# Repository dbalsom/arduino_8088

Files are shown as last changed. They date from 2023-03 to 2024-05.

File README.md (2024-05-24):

# Arduino8088
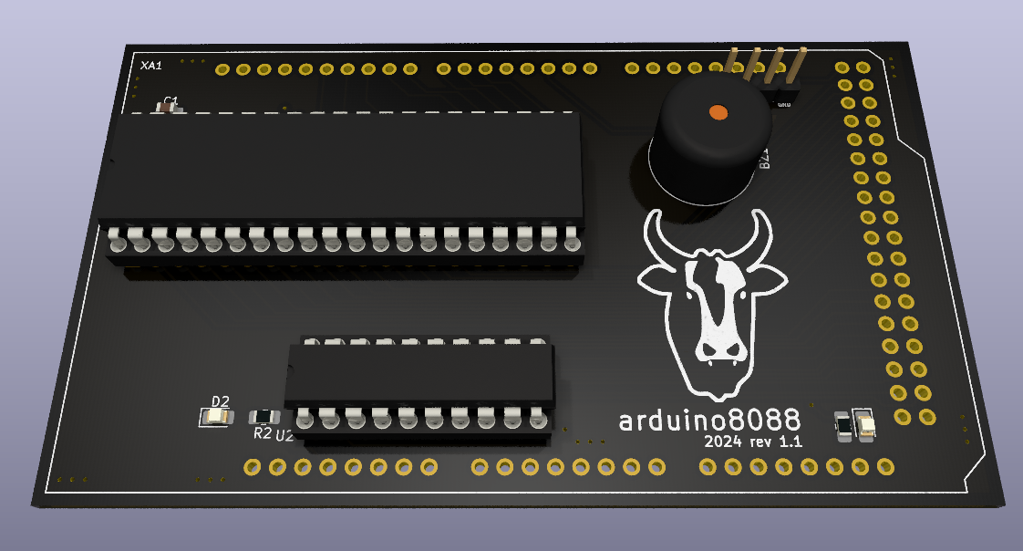
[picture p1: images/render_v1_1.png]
arduino8088_pcb


### About Arduino8088
I've writtten a blog article that gives an overview of this project and how it is used.

https://martypc.blogspot.com/2023/06/hardware-validating-emulator.html

### Description

This project expands on the basic idea of controlling an Intel 8088 or NEC V20 CPU via GPIO pins to clock the CPU and read and write control and data signals.
This can be used to validate an emulator's accuracy, but also as a general method of exploring the operation of 8088 and V20 instructions and timings.

Where it differs from Raspberry Pi based projects is that it uses an Arduino DUE to supply enough GPIO pins to operate the 8088 in Maximum mode without requiring any shifters. This enables several useful signals to be read such as the QS0 & QS1 processor instruction queue status lines, which give us more insight into the internal state of the CPU. We can also enable inputs such as READY, NMI, INTR, and TEST, so we can in theory execute interrupts, emulate wait states, and perhaps simulate FPU and DMA operations.

The board supports an Intel 8288 bus controller which can produce bus signals, but this chip is optional as the sketch can perform i8288 emulation.

The original Arduino8088 board utilized an Arduino MEGA, but this board is now considered deprecated for this project. As of the current release, an [Arduino DUE](https://store.arduino.cc/products/arduino-due) should be used instead. Although the DUE has 3v GPIO, the current board design is modified for 3V operation.  The 80C88 itself tolerates 3V well, and i8288 emulation can be used if you lack a CMOS 8288.

I have been using this project to validate the cycle-accuracy of my PC emulator, MartyPC: https://github.com/dbalsom/martypc 

## Can the CPU be clocked fast enough?

In short, no. We are well past the published minimum cycle times when executing programs via a serial protocol, cycle by cycle. Some chips tolerate this better than others. When working with an Intel branded 8088, I noticed that effective address calculations were failing to add the displacement or index register, but otherwise functioned. I have had more luck with the AMD second-source 8088 CPUs, which seem to function perfectly under slow clocks although they will hang and need to be reset if not cycled for a several milliseconds. The issue is "dynamic logic" - logic gates that lose their state if not refrehsed electrically within a frequent enough interval. To be absolutely safe, it is best to use a fully CMOS process CPU such as the 80C88. 

## Credits

Inspired by and borrows from the Pi8088 validator created by Andreas Jonsson as part of the VirtualXT project:

https://github.com/andreas-jonsson/virtualxt/tree/develop/tools/validator/pi8088

A very similar project is homebrew8088's Raspberry Pi Hat:

https://github.com/homebrew8088/pi86

## To use

If you don't want to order and build the PCB, connect the GPIO pins to the CPU on a breadboard as specified in the KiCad project schematic.

The main Arduino8088 sketch, cpu_server, operates a simple binary serial protocol to execute operations on the CPU and read and write data, status and control signals. This is designed for integration with an emulator or instruction test generator.

Additionally there is a sketch, 'run_program', that will take any user-supplied register state and array of instruction bytes defined in the source code, execute it, and print cycle traces and final register state. This is useful for investigating the timing and operation of certain instructions without needing any external software integrations, however it is restricted in the number of memory reads or writes it can support, due to the limited RAM on the Arduino MEGA (8k!) 'run_program' does not currently support the DUE.

An example client for cpu_server is provded, written in Rust, in the client directory. It demonstrates how to upload arbitrary code to the Arduino8088 and display cycle traces. The client will emulate the entire address space and set up a basic IVT.

## PCB
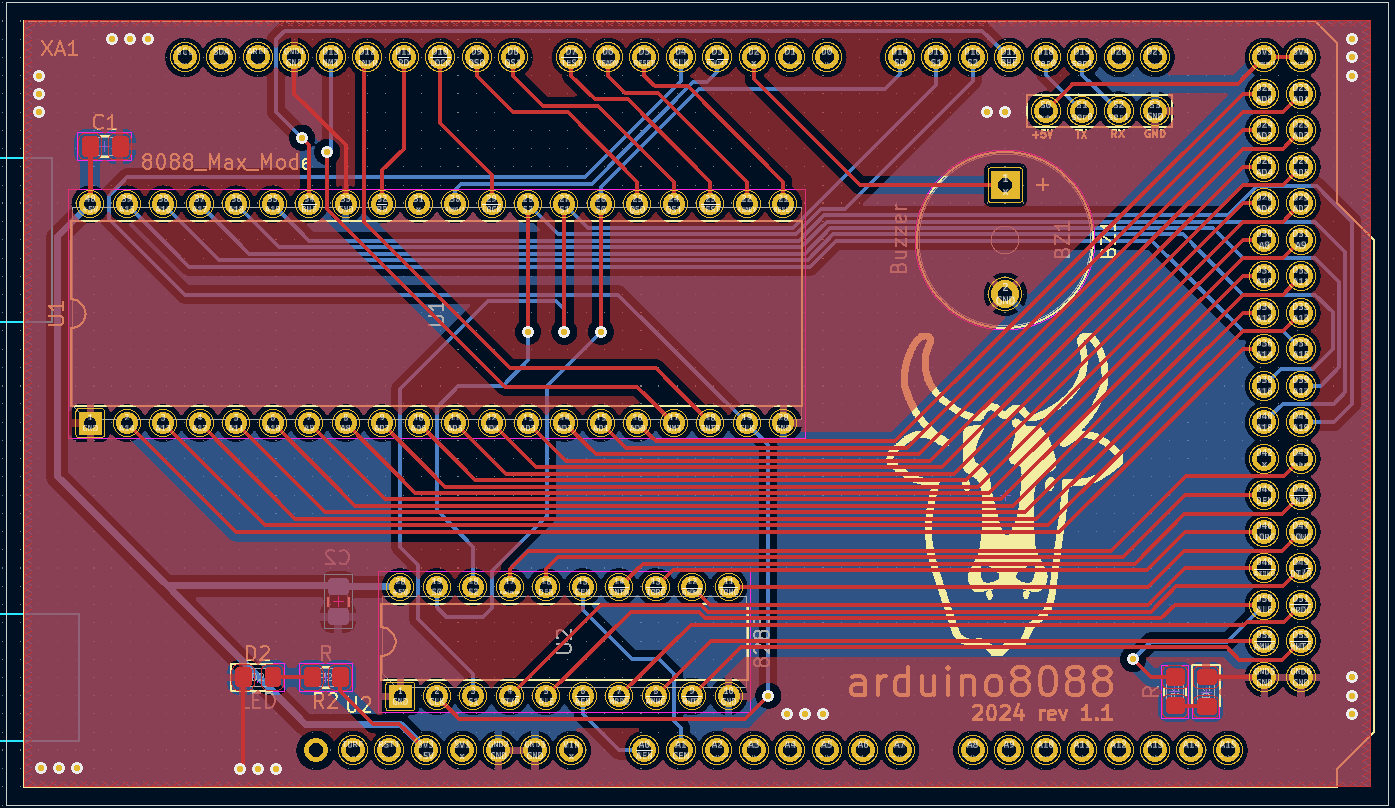
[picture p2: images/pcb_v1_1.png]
pcb_shield50


KiCad project files for the PCB are supplied. 

In theory the board could also support an 8086 CPU. Version 1.1 adds a connection for the 8086's BHE pin, 
which indicates the size of the current bus transfer.  The cpu_server sketch and protocol still needs modification to support 16 bit data transfers and the longer queue length on the 8086.

Please read all the notes in the next section before ordering/assembling parts. Failure to heed warnings will cause damage to your Arduino.

# BOM
- A compatible CPU. For best results, use a CMOS CPU such as a Harris 80C88, Oki 80C88, or NEC V20 CPU. Beware of counterfeits on eBay and other online vendors.
A legitimate chip will not look shiny and new with perfect printing on it.

- (Optional) An Intel 8288 or OKI 82C88 Bus Controller. If not using an 8288, set the EMULATE_8288 flag in cpu_server.

- A set of Arduino stacking headers (also usable with DUE) 
https://www.amazon.com/Treedix-Stacking-Headers-Stackable-Compatible/dp/B08G4FGBPQ

- A DIP-40 and (optionally) DIP-20 socket
  - Optional: You can spring for a ZIF socket such as [https://www.amazon.com/-/en/gp/product/B00B886OZI](https://www.amazon.com/-/en/gp/product/B00B886OZI)

- (2x) 0805 0.047uf bypass capacitors
  https://www.mouser.com/ProductDetail/80-C0805C473KARAUTO

- (Optional) A 12mm, active buzzer with 7.6mm pin spacing. 

  - For DUE: A 3V piezoelectric, low power buzzer <= 6mA
    https://www.mouser.com/ProductDetail/Mallory-Sonalert/PK-11N40PQ?qs=SXHtpsd1MbZ%252B7jeUyAAOVA%3D%3D
    
  - For MEGA: Any 3-5V buzzer <= 30mA
    WARNING: Only connect an electromagnetic buzzer if using an Arduino MEGA.  The DUE has much lower GPIO max current supply.    

- (2x) 750Ohm resistors (for LEDs)
  https://www.mouser.com/ProductDetail/667-ERA-6AED751V

- (2x) Any 0805 ~2V LED of your choice with 1.8-1.9mA forward current
  - https://www.mouser.com/ProductDetail/604-APTD2012LCGCK (Green)
  - https://www.mouser.com/ProductDetail/604-APT2012LSECKJ4RV (Orange)
 
- RS232 board for debug output - choose gender based on your desired cabling
  - https://www.amazon.com/Ultra-Compact-RS232-Converter-1Mbps/dp/B074BMLM11 (male)
  - https://www.amazon.com/Ultra-Compact-RS232-Converter-Female/dp/B074BTGLJN (female)
  - WARNING: DO NOT connect 5V to rs232 board on DUE

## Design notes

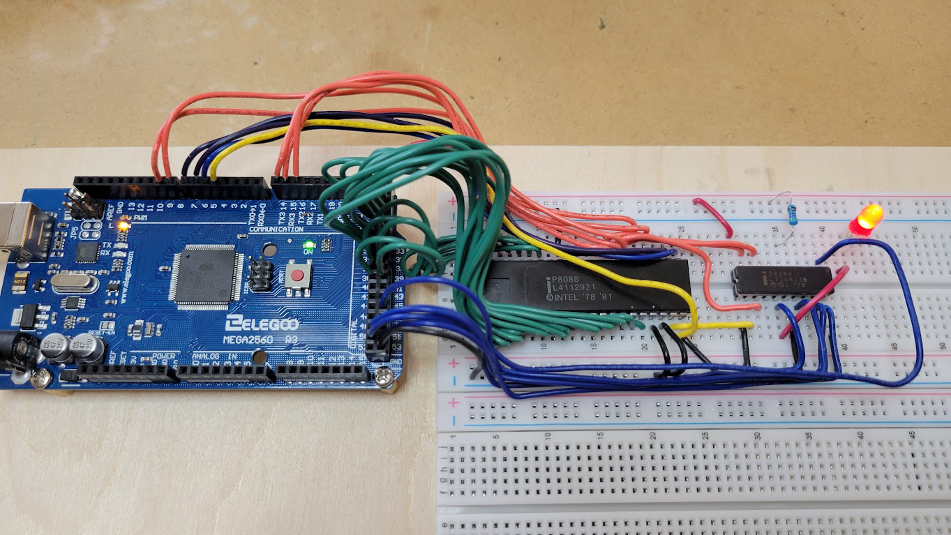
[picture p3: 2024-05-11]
images/arduino8088_breadboard.jpg

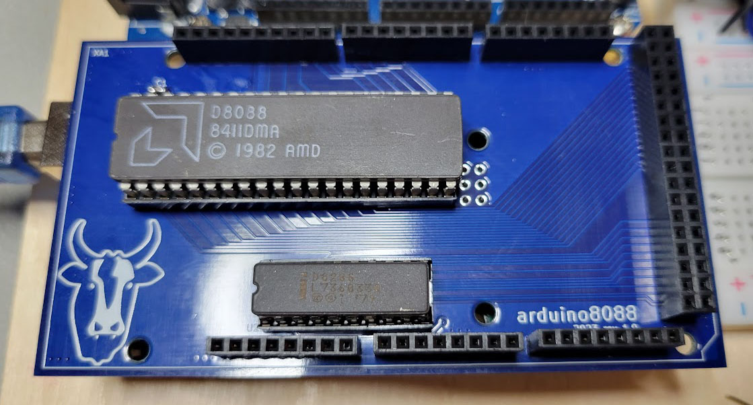
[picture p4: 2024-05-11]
images/arduino8088_pcb.jpg

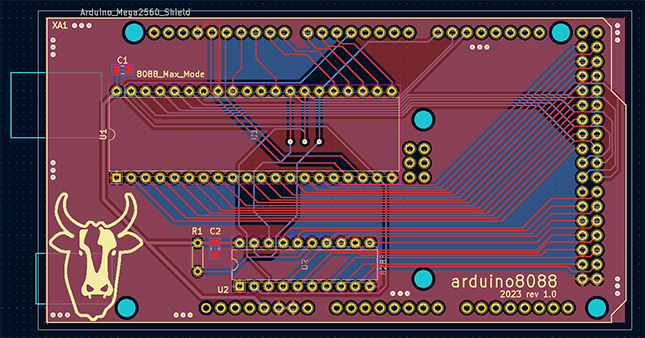
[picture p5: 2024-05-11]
images/pcb_shield50.PNG

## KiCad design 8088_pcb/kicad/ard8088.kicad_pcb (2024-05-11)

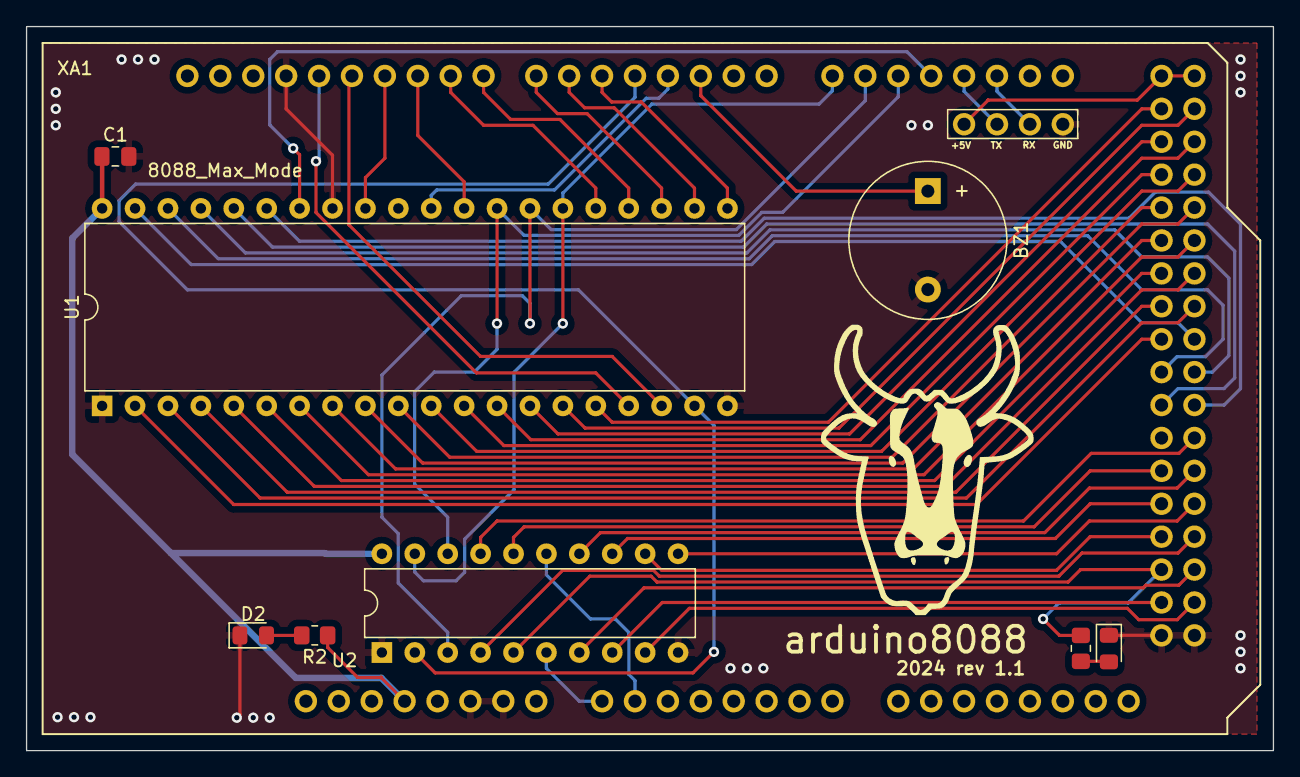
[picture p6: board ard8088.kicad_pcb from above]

Board: 2 copper layers, 96.2 x 55.9 mm, 10 parts (1 on the bottom side), 55 nets.

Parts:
BZ1: Buzzer; Buzzer_12x9.5RM7.6
C1, C2: 0.1uf; C_0805_2012Metric_Pad1.18x1.45mm_HandSolder
D1, D2: LED; LED_0805_2012Metric_Pad1.15x1.40mm_HandSolder
R1, R2: R; R_0805_2012Metric_Pad1.20x1.40mm_HandSolder
U1: 8088_Max_Mode; DIP-40_W15.24mm
U2: 8288; DIP-20_W7.62mm
XA1: Arduino_Mega2560_Shield

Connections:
+5V: C1.1, C2.1, R2.1, U1.40 (VCC), U2.20 (VCC), XA1.3V3 (3.3V)
/+5Vactual: XA1.5V3 (5V), XA1.5V4 (5V), XA1.S0
/A8: U1.8 (A8), XA1.D30
/A9: U1.7 (A9), XA1.D31
/A10: U1.6 (A10), XA1.D32
/A11: U1.5 (A11), XA1.D33
/A12: U1.4 (A12), XA1.D34
/A13: U1.3 (A13), XA1.D35
/A14: U1.2 (A14), XA1.D36
/A15: U1.39 (A15), XA1.D37
/A16: U1.38 (A16/S3), XA1.D38
/A17: U1.37 (A17/S4), XA1.D39
/A18: U1.36 (A18/S5), XA1.D40
/A19: U1.35 (A19/S6), XA1.D41
/AD0: U1.16 (AD0), XA1.D22
/AD1: U1.15 (AD1), XA1.D23
/AD2: U1.14 (AD2), XA1.D24
/AD3: U1.13 (AD3), XA1.D25
/AD4: U1.12 (AD4), XA1.D26
/AD5: U1.11 (AD5), XA1.D27
/AD6: U1.10 (AD6), XA1.D28
/AD7: U1.9 (AD7), XA1.D29
/ALE: R1.1, U2.5 (ALE), XA1.D50
/CEN: U2.15 (CEN), XA1.A1
/CLK: U1.19 (CLK), U2.2 (CLK), XA1.D4
/DEN: U2.16 (DEN), XA1.D44
/DT/~R: U2.4 (DT/~R), XA1.D49
/INTR: U1.18 (INTR), XA1.D12
/MCE/~PDEN: U2.17 (MCE/~PDEN), XA1.D43
/NMI: U1.17 (NMI), XA1.D13
/QS1: U1.24 (QS1), XA1.D8
/QSO: U1.25 (QS0), XA1.D9
/READY: U1.22 (READY), XA1.D6
/RESET: U1.21 (RESET), XA1.D5
/S0: U1.26 (~S0), U2.19 (~S0), XA1.D14 (D14_TX3)
/S1: U1.27 (~S1), U2.3 (~S1), XA1.D15 (D15_RX3)
/S2: U1.28 (~S2), U2.18 (~S2), XA1.D16 (D16_TX2)
/ser0: XA1.D18 (D18_TX1), XA1.S1
/ser1: XA1.D19 (D19_RX1), XA1.S2
/~AEN: U2.6 (~AEN), XA1.A0
/~AIOWC: U2.12 (~AIOWC), XA1.D48
/~AMWC: U2.8 (~AMWC), XA1.D52
/~BHE: U1.34 (HIGH), XA1.D17 (D17_RX2)
/~INTA: U2.14 (~INTA), XA1.D45
/~IORC: U2.13 (~IORC), XA1.D46
/~IOWC: U2.11 (~IOWC), XA1.D47
/~LOCK: U1.29 (~LOCK), XA1.D10
/~MRDC: U2.7 (~MRDC), XA1.D51
/~MWTC: U2.9 (~MWTC), XA1.D53 (D53_SS)
/~RD: U1.32 (~RD), XA1.D11
/~RQ/~GT1: U1.30 (~RQ/~GT1), XA1.D3 (D3_INT1)
/~TEST: U1.23 (~TEST), XA1.D7
GND: BZ1.2 (+), C1.2, C2.2, D1.1 (K), D2.1 (K), U1.1 (GND), U1.20 (GND), U1.33 (MN/~MX), U2.1 (IOB), U2.10 (GND), XA1.GND1 (GND), XA1.GND2 (GND), XA1.GND3 (GND), XA1.GND5 (GND), XA1.GND6 (GND), XA1.S3
unnamed: D1.2 (A), R1.2
unnamed: D2.2 (A), R2.2

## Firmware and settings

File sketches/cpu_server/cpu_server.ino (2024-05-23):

/*
    Arduino8088 Copyright 2022-2024 Daniel Balsom
    https://github.com/dbalsom/arduino_8088

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
    THE SOFTWARE IS PROVIDED “AS IS”, WITHOUT WARRANTY OF ANY KIND, EXPRESS OR
    IMPLIED, INCLUDING BUT NOT LIMITED TO THE WARRANTIES OF MERCHANTABILITY,
    FITNESS FOR A PARTICULAR PURPOSE AND NONINFRINGEMENT. IN NO EVENT SHALL THE
    AUTHORS OR COPYRIGHT HOLDERS BE LIABLE FOR ANY CLAIM, DAMAGES OR OTHER   
    LIABILITY, WHETHER IN AN ACTION OF CONTRACT, TORT OR OTHERWISE, ARISING
    FROM, OUT OF OR IN CONNECTION WITH THE SOFTWARE OR THE USE OR OTHER
    DEALINGS IN THE SOFTWARE.
*/
#include <Arduino.h>
#include "arduino8088.h"
#include "cpu_server.h"
#include "opcodes.h"

static Server SERVER;
static Cpu CPU;
static Intel8288 I8288;

registers LOAD_REGISTERS = {
  0x0000, // AX
  0x0000, // BX
  0x0000, // CX
  0x0000, // DX
  0x0000, // SS
  0x0000, // SP
  0x0000, // FLAGS
  0x0000, // IP
  0xFFFF, // CS
  0x0000, // DS
  0x0000, // ES
  0x0000, // BP
  0x0000, // SI
  0x0000, // DI
};

// Register load routine.
uint8_t LOAD_PROGRAM[] = {
  0x00, 0x00, 0xB8, 0x00, 0x00, 0x8E, 0xD0, 0x89, 0xC4, 0x9D, 0xBB, 0x00, 0x00, 0xB9, 0x00, 0x00,
  0xBA, 0x00, 0x00, 0xB8, 0x00, 0x00, 0x8E, 0xD0, 0xB8, 0x00, 0x00, 0x8E, 0xD8, 0xB8, 0x00, 0x00,
  0x8E, 0xC0, 0xB8, 0x00, 0x00, 0x89, 0xC4, 0xB8, 0x00, 0x00, 0x89, 0xC5, 0xB8, 0x00, 0x00, 0x89,
  0xC6, 0xB8, 0x00, 0x00, 0x89, 0xC7, 0xB8, 0x00, 0x00, 0xEA, 0x00, 0x00, 0x00, 0x00
};

uint8_t JUMP_VECTOR[] = {
  0xEA, 0x00, 0x00, 0x00, 0x00
};

// Patch offsets for load routine
size_t LOAD_BX = 0x0B;
size_t LOAD_CX = 0x0E;
size_t LOAD_DX = 0x11;
size_t LOAD_SS = 0x14;
size_t LOAD_DS = 0x19;
size_t LOAD_ES = 0x1E;
size_t LOAD_SP = 0x23;
size_t LOAD_BP = 0x28;
size_t LOAD_SI = 0x2D;
size_t LOAD_DI = 0x32;
size_t LOAD_AX = 0x37;
size_t LOAD_IP = 0x3A;
size_t LOAD_CS = 0x3C;

// Register store routine.
// Four NOPs have been padded to the front of the STORE routine to hide it from appearing in cycle
// traces (although we'd need 6 for 8086...). 
// We can probably think of a better way to hide STORE program bytes, as this adds several cycles.
const uint8_t STORE_PROGRAM[] = {
  0x90, 0x90, 0x90, 0x90,
  0xE7, 0xFE, 0x89, 0xD8, 0xE7, 0xFE, 0x89, 0xC8, 0xE7, 0xFE, 0x89, 0xD0, 0xE7, 0xFE, 0x8C, 0xD0,
  0xE7, 0xFE, 0x89, 0xE0, 0xE7, 0xFE, 0xB8, 0x00, 0x00, 0x8E, 0xD0, 0xB8, 0x04, 0x00, 0x89, 0xC4,
  0x9C, 0xE8, 0x00, 0x00, 0x8C, 0xC8, 0xE7, 0xFE, 0x8C, 0xD8, 0xE7, 0xFE, 0x8C, 0xC0, 0xE7, 0xFE,
  0x89, 0xE8, 0xE7, 0xFE, 0x89, 0xF0, 0xE7, 0xFE, 0x89, 0xF8, 0xE7, 0xFE, 0xB0, 0xFF, 0xE6, 0xFD
};

uint8_t COMMAND_BUFFER[MAX_COMMAND_BYTES] = {0};

command_func V_TABLE[] = {
  &cmd_version,
  &cmd_reset,
  &cmd_load,
  &cmd_cycle,
  &cmd_read_address_latch,
  &cmd_read_status,
  &cmd_read_8288_command,
  &cmd_read_8288_control,
  &cmd_read_data_bus,
  &cmd_write_data_bus,
  &cmd_finalize,
  &cmd_begin_store,
  &cmd_store,
  &cmd_queue_len,
  &cmd_queue_bytes,
  &cmd_write_pin,
  &cmd_read_pin,
  &cmd_get_program_state,
  &cmd_get_last_error,
  &cmd_get_cycle_state,
  &cmd_cycle_get_cycle_state,
  &cmd_prefetch_store,
  &cmd_read_address,
  &cmd_invalid
};

const size_t MAX_CMD = (sizeof V_TABLE / sizeof (command_func));

char LAST_ERR[MAX_ERR_LEN] = {0};

// Main Sketch setup routine
void setup() {
  SERIAL.begin(BAUD_RATE);
  Serial1.begin(DEBUG_BAUD_RATE);
  while (!SERIAL);
  while (!Serial1);

  // Set all output pins to OUTPUT
  for( int p = 0; p < (sizeof OUTPUT_PINS / sizeof OUTPUT_PINS[0]); p++ ) {
    pinMode(OUTPUT_PINS[p], OUTPUT);
  }
  // Set all input pins to INPUT
  for( int p = 0; p < (sizeof INPUT_PINS / sizeof INPUT_PINS[0]); p++ ) {
    pinMode(INPUT_PINS[p], INPUT);
  }

  // Default output pin states
  digitalWrite(RQ_PIN, HIGH); // Don't allow other bus masters
  digitalWrite(READY_PIN, HIGH);
  digitalWrite(TEST_PIN, LOW);
  digitalWrite(INTR_PIN, LOW); // Must set these to a known value or risk spurious interrupts!
  digitalWrite(NMI_PIN, LOW);  // Must set these to a known value or risk spurious interrupts!
  digitalWrite(AEN_PIN, LOW); // AEN is enable-low
  digitalWrite(CEN_PIN, HIGH); // Command enable enables the outputs on the i8288

  // Wait for CPU to initialize
  delayMicroseconds(100);

  // Patch the reset vector jump
  patch_vector(JUMP_VECTOR, LOAD_SEG);

  CPU.v_state = Reset;

  beep(100);
  Serial1.println("Arduino8088 Server Initialized!");
  clear_error();
  
  SERVER.c_state = WaitingForCommand;
}

void clear_error() {
  strncpy(LAST_ERR, "No error", MAX_ERR_LEN - 1);
}

void set_error(const char *msg) {
  strncpy(LAST_ERR, msg, MAX_ERR_LEN - 1);
  Serial1.println("");
  Serial1.println("************ ERROR ************");
  Serial1.println(LAST_ERR);
  Serial1.println("*******************************");
  error_beep();
}

// Send a failure code byte in reponse to a failed command
void send_fail() {
  #if MODE_ASCII
    SERIAL.write(RESPONSE_CHRS[RESPONSE_FAIL]);
  #else
    SERIAL.write((uint8_t)RESPONSE_FAIL);
  #endif
}

// Send the success code byte in response to a succesful command
void send_ok() {
  #if MODE_ASCII
    SERIAL.write(RESPONSE_CHRS[RESPONSE_OK]);
  #else
    SERIAL.write((uint8_t)RESPONSE_OK);
  #endif
}

void debug_proto(const char* msg) {
  #if DEBUG_PROTO
    Serial1.print("## ");
    Serial1.print(msg);
    Serial1.println(" ##");
  #endif
}

void debug_cmd(const char *cmd, const char* msg) {
  #if DEBUG_PROTO
    Serial1.print("## cmd ");
    Serial1.print(cmd);
    Serial1.print(": " );
    Serial1.print(msg);
    Serial1.println(" ##");
  #endif
}

// Server command - Version
// Send server identifier 'ard8088' followed by protocol version number in binary
bool cmd_version() {
  debug_cmd("VERSION", "In cmd");
  SERIAL.write((uint8_t *)VERSION_DAT, sizeof VERSION_DAT);
  SERIAL.write(VERSION_NUM);
  FLUSH;
  Serial1.println("Got version query!");
  return true;
}

// Server command - Reset
// Attempt to reset the CPU and report status.
// This will be rarely used by itself as the register state is not set up. The Load 
// command will reset the CPU and set register state.
bool cmd_reset() {
  debug_cmd("RESET", "In cmd");
  bool result;
  snprintf(LAST_ERR, MAX_ERR_LEN, "NO ERROR");

  #if EMULATE_8288
    reset_i8288();
  #endif
  result = cpu_reset();
  if(result) {
    change_state(Execute);
  }
  return result;
}

// Server command - Cycle
// Execute a single CPU cycle
bool cmd_cycle() {
  cycle();
  return true;
}

// Server command - Load
// Load the specified register state into the CPU.
// This command takes 28 bytes, which correspond to the word values of each of the 14
// CPU registers.
// Registers should be loaded in the following order, little-endian:
//
// AX, BX, CX, DX, SS, SP, FLAGS, IP, CS, DS, ES, BP, SI, DI
bool cmd_load() {

  //Serial1.println(">> Got load!");
  snprintf(LAST_ERR, MAX_ERR_LEN, "NO ERROR");

  // Sanity check
  if(SERVER.cmd_byte_n < sizeof LOAD_REGISTERS) {
    set_error("Not enough command bytes");
    return false;
  }

  // Write raw command bytes over register struct.
  // All possible bit representations are valid.
  uint8_t *read_p = (uint8_t *)&LOAD_REGISTERS;

  for(size_t i = 0; i < sizeof LOAD_REGISTERS; i++ ) {
    *read_p++ = COMMAND_BUFFER[i];
  }

  patch_load(&LOAD_REGISTERS, LOAD_PROGRAM);
  LOAD_REGISTERS.flags &= CPU_FLAG_DEFAULT_CLEAR;
  LOAD_REGISTERS.flags |= CPU_FLAG_DEFAULT_SET;

  #if EMULATE_8288
    reset_i8288();
  #endif
  bool result = cpu_reset();
  if(!result) {
    //set_error("Failed to reset CPU");
    return false;
  }

  #if USE_LOAD_SEG
    change_state(JumpVector);
  #else
    change_state(Load);
  #endif

  // Run CPU and wait for load to finish
  int load_timeout = 0;
  while(CPU.v_state != Execute) {
    cycle();
    load_timeout++;

    if(load_timeout > 300) {
      // Something went wrong in load program
       set_error("Load timeout");
       return false;
    }
  }

  #if LOAD_INDICATOR
    Serial1.print(".");
  #endif
  debug_proto("LOAD DONE");
  return true;
}

// Server command - ReadAddressLatch
// Read back the contents of the address latch as a sequence of 3 bytes (little-endian)
bool cmd_read_address_latch() {
  static char buf[7];

  #if MODE_ASCII  
    //buf[0] = 0;
    snprintf(
      buf, 7, 
      "%02X%02X%02X",
      (int)(CPU.address_latch & 0xFF),
      (int)((CPU.address_latch >> 8) & 0xFF),
      (int)((CPU.address_latch >> 16) & 0xFF)
    );
    SERIAL.print(buf);
  #else
    SERIAL.write((uint8_t)(CPU.address_latch & 0xFF));
    SERIAL.write((uint8_t)((CPU.address_latch >> 8) & 0xFF));
    SERIAL.write((uint8_t)((CPU.address_latch >> 16) & 0xFF));
  #endif

  return true;
}

// Server command - ReadAddress
// Read back the contents of the address bus as a sequence of 3 bytes (little-endian)
bool cmd_read_address() {
  read_address();
  static char buf[7];

  #if MODE_ASCII  
    //buf[0] = 0;
    snprintf(
      buf, 7, 
      "%02X%02X%02X",
      (int)(CPU.address_bus & 0xFF),
      (int)((CPU.address_bus >> 8) & 0xFF),
      (int)((CPU.address_bus >> 16) & 0xFF)
    );
    SERIAL.print(buf);
  #else
    SERIAL.write((uint8_t)(CPU.address_bus & 0xFF));
    SERIAL.write((uint8_t)((CPU.address_bus >> 8) & 0xFF));
    SERIAL.write((uint8_t)((CPU.address_bus >> 16) & 0xFF));
  #endif

  return true;
}

bool cmd_invalid() {
  Serial1.println("Called cmd_invalid!");
  return false;
}

// Server command - ReadStatus
// Return the value of the CPU status lines S0-S5 and QS0-QS1
bool cmd_read_status() {
  static char buf[3];
  read_status0();
  #if MODE_ASCII  
    snprintf(buf, 3, "%02X", CPU.status0);
    SERIAL.print(buf);
  #else
    SERIAL.write(CPU.status0);
  #endif
  return true;
}

// Server command - Read8288Command
bool cmd_read_8288_command() {
  static char buf[3];
  read_8288_command_bits();
  #if MODE_ASCII  
    snprintf(buf, 3, "%02X", CPU.command_bits);
    SERIAL.print(buf);
  #else
    SERIAL.write(CPU.command_bits);
  #endif
  return true;
}

// Server command - Read8288Control
bool cmd_read_8288_control() {
  static char buf[3];
  read_8288_control_bits();
  #if MODE_ASCII  
    snprintf(buf, 3, "%02X", CPU.control_bits);
    SERIAL.print(buf);
  #else
    SERIAL.write(CPU.control_bits);
  #endif
  return true;
}

// Server command - ReadDataBus
bool cmd_read_data_bus() {
  static char buf[3];
  #if MODE_ASCII  
    snprintf(buf, 3, "%02X", CPU.data_bus);
    SERIAL.print(buf);
  #else
    SERIAL.write(CPU.data_bus);
  #endif

  return true;
}

// Server command - WriteDataBus
// Takes argument of 1 byte
// Writes the specified byte to the data bus.
// This should not be called for CODE fetches after we have called cmd_prefetch_store(), 
// unless a flow control operation occurs that flushes the queue and returns us to 
// within original program boundaries.
bool cmd_write_data_bus() {
  if (CPU.bus_state_latched == CODE) {
    // We've just been instructed to write a normal fetch byte to the bus.
    // If we were prefetching the store program, reset this status as a queue
    // flush must have executed (or we goofed up...)
    CPU.prefetching_store = false;
    CPU.s_pc = 0;
  }


  CPU.data_bus = COMMAND_BUFFER[0];
  CPU.data_type = DATA_PROGRAM;
  return true;
}

// Server command - PrefetchStore
// Instructs the CPU server to load the next byte of the store program early
// Should be called in place of cmd_write_data_bus() by host on T3/TwLast when 
// program bytes have been exhausted.
// (When we are prefetching past execution boundaries during main program execution)
bool cmd_prefetch_store() {
  if (CPU.s_pc >= sizeof STORE_PROGRAM) {
    set_error("Store program underflow");
    return false;
  }
  CPU.prefetching_store = true;
  CPU.data_bus = STORE_PROGRAM[CPU.s_pc];
  // s_pc is advanced during cycle() to avoid duplicated increments
  #if DEBUG_STORE
    Serial1.print("## PREFETCH_STORE: s_pc: ");
    Serial1.print(CPU.s_pc);
    Serial1.print(" addr: ");
    Serial1.print(CPU.address_latch, 16);
    Serial1.print(" byte: ");
    Serial1.println(STORE_PROGRAM[CPU.s_pc], 16);
  #endif

  CPU.data_type = DATA_PROGRAM_END;
  return true;
}

// Server command - Finalize
// Sets the data bus flag to DATA_PROGRAM_END, so that the Execute state can terminate
// on the next instruction queue fetch
bool cmd_finalize() {
  if(CPU.v_state == Execute) {
    change_state(ExecuteFinalize);

    // Wait for execute done state
    int execute_timeout = 0;
    while(CPU.v_state != ExecuteDone) {
      cycle();
      execute_timeout++;
      if(execute_timeout > FINALIZE_TIMEOUT) {
        set_error("cmd_finalize: state timeout");
        return false;
      }
    }
    return true;
  }
  else {
    error_beep();
    set_error("cmd_finalize: wrong state: ");
    Serial1.println(CPU.v_state);
    return false;
  }
}

// Server command - BeginStore
// Execute state must be in ExecuteDone before intiating BeginStore command
//
bool cmd_begin_store(void) {
  /*
  char err_msg[30];

  // Command only valid in ExecuteDone state
  if(CPU.v_state != ExecuteDone) {
    snprintf(err_msg, 30, "BeginStore: Wrong state: %d ", CPU.v_state);
    set_error(err_msg);
    return false;
  }

  change_state(Store);
  */
  return true;
}

// Server command - Store
// 
// Returns values of registers in the following order, little-endian
// AX, BX, CX, DX, SS, SP, FLAGS, IP, CS, DS, ES, BP, SI, DI
// Execute state must be in StoreDone before executing Store command
bool cmd_store(void) {

  #if DEBUG_STORE
    Serial1.print("IN STORE: s_pc is: ");
    Serial1.println(CPU.s_pc);
  #endif

  char err_msg[30];
  // Command only valid in Store
  if(CPU.v_state != ExecuteDone) {
    snprintf(err_msg, 30, "Store: Wrong state: %d ", CPU.v_state);

    set_error(err_msg);
    return false;
  }

  change_state(Store);

  int store_timeout = 0;

  // Cycle CPU until Store complete
  while(CPU.v_state != StoreDone) {
    cycle();
    store_timeout++;

    if (store_timeout > 500) {
      Serial1.println("## STORE: Timeout! ##");
      snprintf(err_msg, 30, "StoreDone timeout.");
      error_beep();
      return false;
    }
  }

  // Dump final register state to Serial port
  uint8_t *reg_p = (uint8_t *)&CPU.post_regs;
  for(size_t i = 0; i < sizeof CPU.post_regs; i++ ) {
    SERIAL.write(reg_p[i]);
  }

  #if STORE_INDICATOR
    Serial1.print("?");
  #endif
  change_state(Done);
  return true;
}


// Server command - QueueLen
// Return the length of the instruction queue in bytes
bool cmd_queue_len(void) {

  SERIAL.write((uint8_t)CPU.queue.len);
  return true;
}

// Server command - QueueBytes
// Return the contents of the instruction queue, from 0-4 bytes.
bool cmd_queue_bytes(void) {

  for(size_t i = 0; i < CPU.queue.len; i++ ) {
    SERIAL.write(read_queue(i));
  }
  return true;
}

// Server command - Write pin
// Sets the value of the specified CPU input pin
bool cmd_write_pin(void) {

  uint8_t pin_idx = COMMAND_BUFFER[0];
  uint8_t pin_val = COMMAND_BUFFER[1] & 0x01;

  if(pin_idx < sizeof WRITE_PINS) {
    uint8_t pin_no = WRITE_PINS[pin_idx];

    switch(pin_no) {
      case READY_PIN:
        WRITE_READY_PIN(pin_val);
        break;

      case TEST_PIN:
        WRITE_TEST_PIN(pin_val);
        break;

      case INTR_PIN:
        WRITE_INTR_PIN(pin_val);
        break;

      case NMI_PIN:
        WRITE_NMI_PIN(pin_val);
        break;
      
      default:
        error_beep();
        return false;
    }
    return true;
  }
  else {
    // Invalid pin 
    error_beep();
    return false;
  }
}

// Server command - Read pin
bool cmd_read_pin(void) {
  // Not implemented
  SERIAL.write((uint8_t)0);
  return true;
}

// Server command - Get program state
bool cmd_get_program_state(void) {
  SERIAL.write((uint8_t)CPU.v_state);
  return true;
}

// Server command - Get last error
bool cmd_get_last_error(void) {
  SERIAL.write(LAST_ERR);
  return true;
}

// Server command - Get Cycle State
// A combination of all the status info typically needed for a single cycle
// Returns 4 bytes
bool cmd_get_cycle_state(void) {
  read_status0();
  read_8288_command_bits();
  read_8288_control_bits();
  uint8_t byte0 = ((uint8_t)CPU.v_state & 0x0F) << 4;
  byte0 |= (CPU.control_bits & 0x0F);

  SERIAL.write(byte0);
  SERIAL.write(CPU.status0);
  SERIAL.write(CPU.command_bits);
  #if(DATA_BUS_SIZE == 1)
    //debug_proto("Sending one byte of data bus");
    SERIAL.write(CPU.data_bus);
  #else
    SERIAL.write(uint8_t(CPU.data_bus >> 8));
    SERIAL.write(uint8_t(CPU.data_bus & 0xFF));
  #endif

  return true;
}

// Server command - Cycle and Get Cycle State
// Cycle the CPU + return A combination of all the status info typically needed for a single cycle
// Returns 4 bytes
bool cmd_cycle_get_cycle_state(void) {
  cycle();
  read_status0();
  read_8288_command_bits();
  read_8288_control_bits();
  uint8_t byte0 = ((uint8_t)CPU.v_state & 0x0F) << 4;
  byte0 |= (CPU.control_bits & 0x0F);

  SERIAL.write(byte0);
  SERIAL.write(CPU.status0);
  SERIAL.write(CPU.command_bits);
  #if(DATA_BUS_SIZE == 1)
    debug_proto("writing one byte of data bus");
    SERIAL.write(CPU.data_bus);
  #else
    SERIAL.write(uint8_t(CPU.data_bus >> 8));
    SERIAL.write(uint8_t(CPU.data_bus & 0xFF));
  #endif

  return true;
}

void patch_vector(uint8_t *vec, uint16_t seg) {
  *((uint16_t *)&vec[3]) = seg;
}

void patch_load(registers *reg, uint8_t *prog) {
  *((uint16_t *)prog) = reg->flags;
  *((uint16_t *)&prog[LOAD_BX]) = reg->bx;
  *((uint16_t *)&prog[LOAD_CX]) = reg->cx;
  *((uint16_t *)&prog[LOAD_DX]) = reg->dx;
  *((uint16_t *)&prog[LOAD_SS]) = reg->ss;
  *((uint16_t *)&prog[LOAD_DS]) = reg->ds;
  *((uint16_t *)&prog[LOAD_ES]) = reg->es;
  *((uint16_t *)&prog[LOAD_SP]) = reg->sp;
  *((uint16_t *)&prog[LOAD_BP]) = reg->bp;
  *((uint16_t *)&prog[LOAD_SI]) = reg->si;
  *((uint16_t *)&prog[LOAD_DI]) = reg->di;
  *((uint16_t *)&prog[LOAD_AX]) = reg->ax;
  *((uint16_t *)&prog[LOAD_IP]) = reg->ip;
  *((uint16_t *)&prog[LOAD_CS]) = reg->cs;
}
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
void loop() {
  
  switch(SERVER.c_state) {

    case WaitingForCommand:
      if(SERIAL.available() > 0) {
        uint8_t cmd_byte = SERIAL.read();

        debug_cmd(CMD_STRINGS[cmd_byte], "received!");

        bool got_command = false;
        if(cmd_byte >= (uint8_t)CmdInvalid) {
          // Command is out of range, check against alias list
          for( uint8_t a = 0; a < sizeof CMD_ALIASES; a++) {
            if(cmd_byte == CMD_ALIASES[a]) {
              /*
              SERIAL.print("Got command alias: ");
              SERIAL.println(cmd_byte, HEX);
              */
              cmd_byte = a;
              got_command = true;
              break;
            }
          }

          if(!got_command) {
            send_fail();
            break;
          }
        }
        
        // Valid command, enter ReadingCommand state
        SERVER.cmd = (server_command)cmd_byte;

        if(cmd_byte == 0) {
          // We ignore command byte 0 (null command)
          break;
        }
        else if (cmd_byte > MAX_CMD) {
          // Cmd is out of range
          debug_proto("Command out of range!");
          break;
        }
        else if(CMD_INPUTS[cmd_byte] > 0) {
          // This command requires input bytes before it is executed.
          SERVER.cmd = (server_command)cmd_byte;
          SERVER.cmd_byte_n = 0;
          SERVER.c_state = ReadingCommand;
          SERVER.cmd_bytes_expected = CMD_INPUTS[cmd_byte];
          SERVER.cmd_start_time = millis(); // Get start time for timeout calculation
        }
        else {
          // Command requires no input, execute immediately
          bool result = V_TABLE[cmd_byte - 1]();
          if(result) {  
            debug_proto("Command OK!");
            send_ok();
          }
          else {
            debug_proto("Command FAIL!");
            send_fail();
          }
        }
      }
      break;

    case ReadingCommand:
      // The previously specified command requires paramater bytes, so read them in, or timeout
      if(SERIAL.available() > 0) {
        uint8_t cmd_byte = SERIAL.read();
        
        if(SERVER.cmd_byte_n < MAX_COMMAND_BYTES) {
          // Stil have bytes yet to read
          COMMAND_BUFFER[SERVER.cmd_byte_n] = cmd_byte;
          SERVER.cmd_byte_n++;
 
          if(SERVER.cmd_byte_n == SERVER.cmd_bytes_expected) {
            // We have received enough parameter bytes to execute the in-progress command.
            bool result = V_TABLE[SERVER.cmd - 1]();
            if(result) {  
              send_ok();
            }
            else {
              send_fail();
            }

            // Revert to listening for command
            SERVER.cmd_byte_n = 0;
            SERVER.cmd_bytes_expected = 0;
            SERVER.c_state = WaitingForCommand;
          }
        }
      }
      else {
        // No bytes received yet, so keep track of how long we've been waiting
        uint32_t now = millis();
        uint32_t elapsed = now - SERVER.cmd_start_time;

        if(elapsed >= CMD_TIMEOUT) {
          // Timed out waiting for parameter bytes. Send failure and revert to listening for command
          SERVER.cmd_byte_n = 0;
          SERVER.cmd_bytes_expected = 0;          
          SERVER.c_state = WaitingForCommand;
          debug_proto("Command timeout!");
          send_fail();
        }
      }
      break;
  }
}

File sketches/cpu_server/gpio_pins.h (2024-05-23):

/*
    Arduino8088 Copyright 2022-2024 Daniel Balsom
    https://github.com/dbalsom/arduino_8088

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
    THE SOFTWARE IS PROVIDED “AS IS”, WITHOUT WARRANTY OF ANY KIND, EXPRESS OR
    IMPLIED, INCLUDING BUT NOT LIMITED TO THE WARRANTIES OF MERCHANTABILITY,
    FITNESS FOR A PARTICULAR PURPOSE AND NONINFRINGEMENT. IN NO EVENT SHALL THE
    AUTHORS OR COPYRIGHT HOLDERS BE LIABLE FOR ANY CLAIM, DAMAGES OR OTHER   
    LIABILITY, WHETHER IN AN ACTION OF CONTRACT, TORT OR OTHERWISE, ARISING
    FROM, OUT OF OR IN CONNECTION WITH THE SOFTWARE OR THE USE OR OTHER
    DEALINGS IN THE SOFTWARE.
*/
#ifndef _ARDUINO8088_PINS_H
#define _ARDUINO8088_PINS_H

#define BIT00  (1u << 0)
#define BIT01  (1u << 1)
#define BIT02  (1u << 2)
#define BIT03  (1u << 3)
#define BIT04  (1u << 4)
#define BIT05  (1u << 5)
#define BIT06  (1u << 6)
#define BIT07  (1u << 7)
#define BIT08  (1u << 8)
#define BIT09  (1u << 9)
#define BIT10  (1u << 10)
#define BIT11  (1u << 11)
#define BIT12  (1u << 12)
#define BIT13  (1u << 13)
#define BIT14  (1u << 14)
#define BIT15  (1u << 15)
#define BIT16  (1u << 16)
#define BIT17  (1u << 17)
#define BIT18  (1u << 18)
#define BIT19  (1u << 19)
#define BIT20  (1u << 20)
#define BIT21  (1u << 21)
#define BIT22  (1u << 22)
#define BIT23  (1u << 23)
#define BIT24  (1u << 24)
#define BIT25  (1u << 25)
#define BIT26  (1u << 26)
#define BIT27  (1u << 27)
#define BIT28  (1u << 28)
#define BIT29  (1u << 29)
#define BIT30  (1u << 30)
#define BIT31  (1u << 31)

#define SET_BIT00  (1u << 0)
#define SET_BIT01  (1u << 1)
#define SET_BIT02  (1u << 2)
#define SET_BIT03  (1u << 3)
#define SET_BIT04  (1u << 4)
#define SET_BIT05  (1u << 5)
#define SET_BIT06  (1u << 6)
#define SET_BIT07  (1u << 7)
#define SET_BIT08  (1u << 8)
#define SET_BIT09  (1u << 9)
#define SET_BIT10  (1u << 10)
#define SET_BIT11  (1u << 11)
#define SET_BIT12  (1u << 12)
#define SET_BIT13  (1u << 13)
#define SET_BIT14  (1u << 14)
#define SET_BIT15  (1u << 15)

#define CLR_BIT00  ((1u << 0) << 16)
#define CLR_BIT01  ((1u << 1) << 16)
#define CLR_BIT02  ((1u << 2) << 16)
#define CLR_BIT03  ((1u << 3) << 16)
#define CLR_BIT04  ((1u << 4) << 16)
#define CLR_BIT05  ((1u << 5) << 16)
#define CLR_BIT06  ((1u << 6) << 16)
#define CLR_BIT07  ((1u << 7) << 16)
#define CLR_BIT08  ((1u << 8) << 16)
#define CLR_BIT09  ((1u << 9) << 16)
#define CLR_BIT10  ((1u << 10) << 16)
#define CLR_BIT11  ((1u << 11) << 16)
#define CLR_BIT12  ((1u << 12) << 16)
#define CLR_BIT13  ((1u << 13) << 16)
#define CLR_BIT14  ((1u << 14) << 16)
#define CLR_BIT15  ((1u << 15) << 16)

#if defined (ARDUINO_GIGA)
    // If Arduino GIGA

#elif defined(__SAM3X8E__) 
    // If Arduino DUE

    #define READ_PIN_D14      ((PIOD->PIO_PDSR & BIT04) != 0)
    #define READ_PIN_D15      ((PIOD->PIO_PDSR & BIT05) != 0)
    #define READ_PIN_D16      ((PIOA->PIO_PDSR & BIT13) != 0)

    #define READ_PIN_D09       ((PIOC->PIO_PDSR & BIT21) != 0)
    #define READ_PIN_D08       ((PIOC->PIO_PDSR & BIT22) != 0)

    #define READ_PIN_D38      ((PIOC->PIO_PDSR & BIT06) != 0)
    #define READ_PIN_D39      ((PIOC->PIO_PDSR & BIT07) != 0)
    #define READ_PIN_D40      ((PIOC->PIO_PDSR & BIT08) != 0)

    #define READ_PIN_D45      ((PIOC->PIO_PDSR & BIT18) != 0)
    #define READ_PIN_D46      ((PIOC->PIO_PDSR & BIT17) != 0)
    #define READ_PIN_D47      ((PIOC->PIO_PDSR & BIT16) != 0)
    #define READ_PIN_D48      ((PIOC->PIO_PDSR & BIT15) != 0)
    
    #define READ_PIN_D50      ((PIOC->PIO_PDSR & BIT13) != 0)
    #define READ_PIN_D51      ((PIOC->PIO_PDSR & BIT12) != 0)
    #define READ_PIN_D52      ((PIOB->PIO_PDSR & BIT21) != 0)
    #define READ_PIN_D53      ((PIOB->PIO_PDSR & BIT14) != 0)

#elif defined(__AVR_ATmega2560__) 
    // If Arduino MEGA
    #define READ_PIN_D08  ((PINH & BIT5) != 0) // QS1 - Pin 8 (H5)
    #define READ_PIN_D09  ((PINH & BIT6) != 0) // QS0 - Pin 9 (H6)

    #define READ_PIN_D14  ((PINJ & BIT1) != 0) // S0  - Pin 14
    #define READ_PIN_D15  ((PINJ & BIT0) != 0) // S1  - Pin 15
    #define READ_PIN_D16  ((PINH & BIT1) != 0) // S2  - Pin 16 (H1)
    #define READ_PIN_D38  ((PIND & BIT7) != 0) // S3  - Pin 38 (D7)
    #define READ_PIN_D39  ((PING & BIT2) != 0) // S4  - Pin 39 (G2)
    #define READ_PIN_D40  ((PING & BIT1) != 0) // S5  - Pin 40 (G1)
    
    #define READ_PIN_A0   ((PINF & 0x01) != 0)
    #define READ_PIN_A1   ((PINF & 0x02) != 0)
    #define READ_PIN_D50  ((PINB & 0x08) != 0)
    #define READ_PIN_D51  ((PINB & 0x04) != 0)
    #define READ_PIN_D52  ((PINB & 0x02) != 0)
    #define READ_PIN_D53  ((PINB & 0x01) != 0)
    #define READ_PIN_D46  ((PINL & 0x08) != 0)
    #define READ_PIN_D48  ((PINL & 0x02) != 0)
    #define READ_PIN_D47  ((PINL & 0x04) != 0)
    #define READ_PIN_D45  ((PINL & 0x10) != 0)
#endif

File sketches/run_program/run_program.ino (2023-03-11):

/*
  (C)2023 Daniel Balsom
  https://github.com/dbalsom/arduino_8088

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
*/
#include "arduino8088.h"
#include "opcodes.h"

// ------------------------- User-provided state ------------------------------

// Define the initial register state to load here.
// Reserved flags will be set for you.
registers LOAD_REGISTERS = {
  0xFFFF, // AX
  0x5000, // BX
  0x0002, // CX
  0x7000, // DX
  0x1000, // SS
  0xFFFF, // SP
  0x0000, // FLAGS
  0x0000, // IP
  0xF000, // CS
  0x2000, // DS
  0x3000, // ES
  0x0001, // BP
  0x1000, // SI
  0x0003, // DI
};

// Write the program to execute here, to start at the provided CS:IP.
const unsigned char CODE_SEGMENT[] = {  
  //0xB0, 0xA7, 0x2C, 0xD0 // mov al, 0xa7; sub al, 0xd0
  0xF9, 0xB0, 0xA7, 0x1C, 0xCF, // stc, mov al, 0xa7; sbb al, 0xcf
  //0xFF, 0x20, 0x90, 0x90
  //0x40, 0x40, 0x40, 0x40, 0x90, 0x90, 0x90
};

// Specify how many bytes of CODE_SEGMENT to have prefetched before execution begins
// This value must be <= the length of CODE_SEGMENT
size_t PREFETCH_LEN = 4;

// -----------------------End User-provided state -----------------------------

static Cpu CPU;
registers INITIAL_REGISTERS;

// Register load routine.
static u8 LOAD_PROGRAM[] = {
  0x00, 0x00, 0xB8, 0x00, 0x00, 0x8E, 0xD0, 0x89, 0xC4, 0x9D, 0xBB, 0x00, 0x00, 0xB9, 0x00, 0x00,
  0xBA, 0x00, 0x00, 0xB8, 0x00, 0x00, 0x8E, 0xD0, 0xB8, 0x00, 0x00, 0x8E, 0xD8, 0xB8, 0x00, 0x00,
  0x8E, 0xC0, 0xB8, 0x00, 0x00, 0x89, 0xC4, 0xB8, 0x00, 0x00, 0x89, 0xC5, 0xB8, 0x00, 0x00, 0x89,
  0xC6, 0xB8, 0x00, 0x00, 0x89, 0xC7, 0xB8, 0x00, 0x00, 0xEA, 0x00, 0x00, 0x00, 0x00
};

static u8 JUMP_VECTOR[] = {
  0xEA, 0x00, 0x00, 0x00, 0x00
};

// Prefetch programs.
// We need an instruction that fetches one more byte then the length of the instruction.
// We use an 'or al, *' instruction here, manipulating the modrm to adjust the length of
// the EA calculation so that the first prefetched byte is executed in a t1 state.

// 0 is fed to OR so that al is not changed. However, this does overwrite flags, so POPF
// is used to reset the flag state. Luckily, POPF fetches one more byte so this works out
// for us nicely. The only issue is there appears to be a delay when a byte is fetched 
// from a full queue - POPF from a full queue will not fetch a code byte. I haven't 
// thought of a way around this yet, so for now, flags can only be preserved if prefetching
// 1-3 bytes.

size_t PREFETCH_PROGRAM_LEN = 0;
size_t PREFETCH_STACK_ADJUST = 0;
u8 *PREFETCH_PROGRAM = NULL;

// Program to set up 1 byte in prefetch and pop flags
static u8 PREFETCH_1[] = {
  0x0A, 0xC0, 0x9D
};

// Program to set up 2 bytes in prefetch and pop flags
static u8 PREFETCH_2[] = {
  0x0A, 0x0A, 0x9D, 0x90, 0x90, 0x90, 0x90
};

// Program to set up 3 bytes in prefetch and pop flags
static u8 PREFETCH_3[] = {
  0x0A, 0x02, 0x0A, 0x04, 0x9D
};

// Program to set up 4 bytes in prefetch
// NOTE: does not preserve flags due to fetch delays after full queue
static u8 PREFETCH_4[] = {
  0x0A, 0x02, 0x0A, 0x02, 0x0A, 0x02
};

// Patch offsets for load routine
size_t LOAD_BX = 0x0B;
size_t LOAD_CX = 0x0E;
size_t LOAD_DX = 0x11;
size_t LOAD_SS = 0x14;
size_t LOAD_DS = 0x19;
size_t LOAD_ES = 0x1E;
size_t LOAD_SP = 0x23;
size_t LOAD_BP = 0x28;
size_t LOAD_SI = 0x2D;
size_t LOAD_DI = 0x32;
size_t LOAD_AX = 0x37;
size_t LOAD_IP = 0x3A;
size_t LOAD_CS = 0x3C;

// Register store routine.
static const u8 STORE_PROGRAM[] = {
  0xE7, 0xFE, 0x89, 0xD8, 0xE7, 0xFE, 0x89, 0xC8, 0xE7, 0xFE, 0x89, 0xD0, 0xE7, 0xFE, 0x8C, 0xD0,
  0xE7, 0xFE, 0x89, 0xE0, 0xE7, 0xFE, 0xB8, 0x00, 0x00, 0x8E, 0xD0, 0xB8, 0x04, 0x00, 0x89, 0xC4,
  0x9C, 0xE8, 0x00, 0x00, 0x8C, 0xC8, 0xE7, 0xFE, 0x8C, 0xD8, 0xE7, 0xFE, 0x8C, 0xC0, 0xE7, 0xFE,
  0x89, 0xE8, 0xE7, 0xFE, 0x89, 0xF0, 0xE7, 0xFE, 0x89, 0xF8, 0xE7, 0xFE, 0xB0, 0xFF, 0xE6, 0xFD
};

u32 RAM_ADDRESSES[RAM_SIZE] = {0};
u8 RAM[RAM_SIZE] = {0};

void setup() {
  Serial.begin(BAUD_RATE);

  // Set all output pins to OUTPUT
  for( int p = 0; p < (sizeof OUTPUT_PINS / sizeof OUTPUT_PINS[0]); p++ ) {
    pinMode(OUTPUT_PINS[p], OUTPUT);
  }
  // Set all input pins to INPUT
  for( int p = 0; p < (sizeof INPUT_PINS / sizeof INPUT_PINS[0]); p++ ) {
    pinMode(INPUT_PINS[p], INPUT);
  }

  // Default output pin states
  digitalWrite(RQ_PIN, HIGH); // Don't allow other bus masters
  digitalWrite(READY_PIN, HIGH); // Ready is always high for now - todo: simulate wait states?
  digitalWrite(TEST_PIN, LOW);
  digitalWrite(INTR_PIN, LOW); // Must set these to a known value or risk spurious interrupts!
  digitalWrite(NMI_PIN, LOW);  // Must set these to a known value or risk spurious interrupts!
  digitalWrite(AEN_PIN, LOW); // AEN is enable-low
  digitalWrite(CEN_PIN, HIGH); // Command enable enables the outputs on the i8288

  // Wait for CPU to initialize
  delayMicroseconds(100);

  // Patch the reset vector jump
  patch_vector(JUMP_VECTOR, LOAD_SEG);

  CPU.v_state = Reset;
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

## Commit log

2022-12-23 Initial commit of kicad project
    [ard8088.kicad_pcb, ard8088.kicad_sch]
2022-12-25 Revamp cycle trace output
2023-01-01 Finalize op, debug buzzer
    [arduino8088.h, cpu_server.h, cpu_server.ino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]
2023-02-10 Update README for release of PCB
2023-02-10 Minor updates, release PCB
    [ard8088.kicad_pcb, ard8088.kicad_sch]
2023-03-11 Update schematic to 1.0b
    [ard8088.kicad_sch]
2023-03-11 fix overlapping ascii cmd
    [cpu_server.h]
2023-03-11 Fix INTA pin read
    [lib.ino]
2023-03-11 Fix resetting for PCB
    [run_program.ino]
2023-03-11 add RQ pin
2024-05-11 update kicad project
    [ard8088.kicad_pcb, ard8088.kicad_sch]

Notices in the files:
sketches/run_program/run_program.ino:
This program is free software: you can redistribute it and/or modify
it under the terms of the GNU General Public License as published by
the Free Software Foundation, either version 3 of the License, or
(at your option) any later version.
